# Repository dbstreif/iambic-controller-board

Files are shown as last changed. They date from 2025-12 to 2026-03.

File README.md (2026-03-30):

# Iambic Controller Custom Hardware
### (Morse Code Keyer Hardware Interface)

A board design using ATtiny85 microcontroller that interfaces with an iambic CW keyer over TRS to USB.
This project provides hardware for the firmware project found here: [Iambic-Controller](https://github.com/dbstreif/iambic-controller)

To build and install on your microcontroller, please use the Arduino IDE with the Digistump additional boards manager:
[Digistump Additional Boards Manager](https://raw.githubusercontent.com/digistump/arduino-boards-index/master/package_digistump_index.json)

### Compatibility
Plug and play with VBand, MorseIT (IOS/Android), MorseKeyer Software (PC), and many other applications.

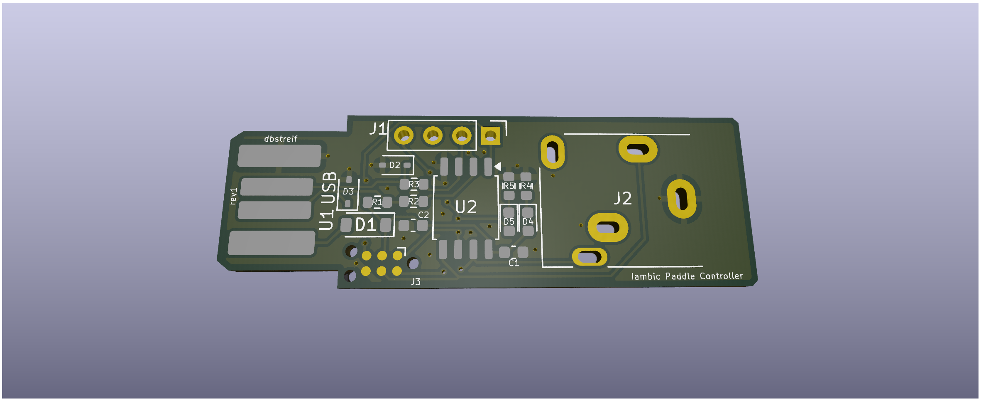
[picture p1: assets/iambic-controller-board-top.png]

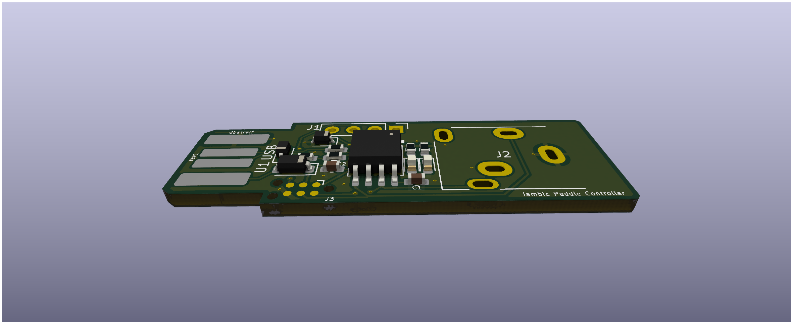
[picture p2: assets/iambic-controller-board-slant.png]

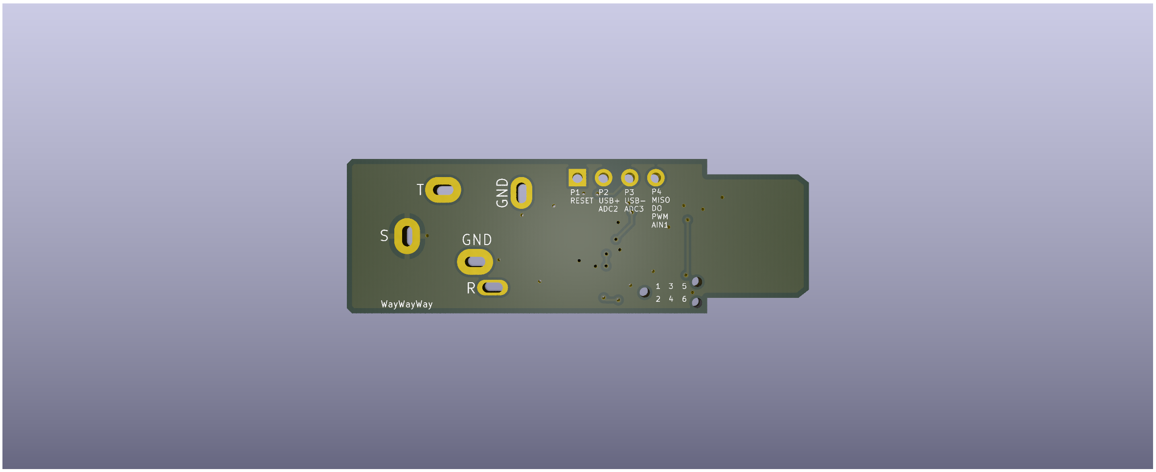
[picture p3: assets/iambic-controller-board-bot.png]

[Video of Device in Action](https://drive.google.com/file/d/1ocy6Hf0ZipwWTclOcQ86UAAeljgz8sle/view?usp=sharing)

Shield: [][cc-by]

This work is licensed under a
[Creative Commons Attribution 4.0 International License][cc-by].

[][cc-by]

[cc-by]: http://creativecommons.org/licenses/by/4.0/
[cc-by-image]: https://i.creativecommons.org/l/by/4.0/88x31.png
[cc-by-shield]: https://img.shields.io/badge/License-CC%20BY%204.0-lightgrey.svg

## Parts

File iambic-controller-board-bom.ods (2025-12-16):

Id | Designator | Footprint | Quantity | Designation | Manufacturer | MPN
1 | D5 | LED_0603_1608Metric | 1 | LED2 | Diodes Inc. | BZT52C3V6S-7-F
2 | R1 | R_0603_1608Metric | 1 | 1K5
3 | D1 | D_SOD-123 | 1 | 1N5819 | Diodes Inc. | 1N58
4 | R5,R4 | R_0603_1608Metric | 2 | 1K
5 | D4 | LED_0603_1608Metric | 1 | LED1
6 | R2,R3 | R_0603_1608Metric | 2 | 68R
7 | D2,D3 | D_SOD-323 | 2 | 3V6
8 | C1 | C_0603_1608Metric | 1 | 100nF
9 | C2 | C_0603_1608Metric | 1 | 10uF
10 | U2 | SOIC-8_5.3x5.3mm_P1.27mm | 1 | ATtiny85-20S

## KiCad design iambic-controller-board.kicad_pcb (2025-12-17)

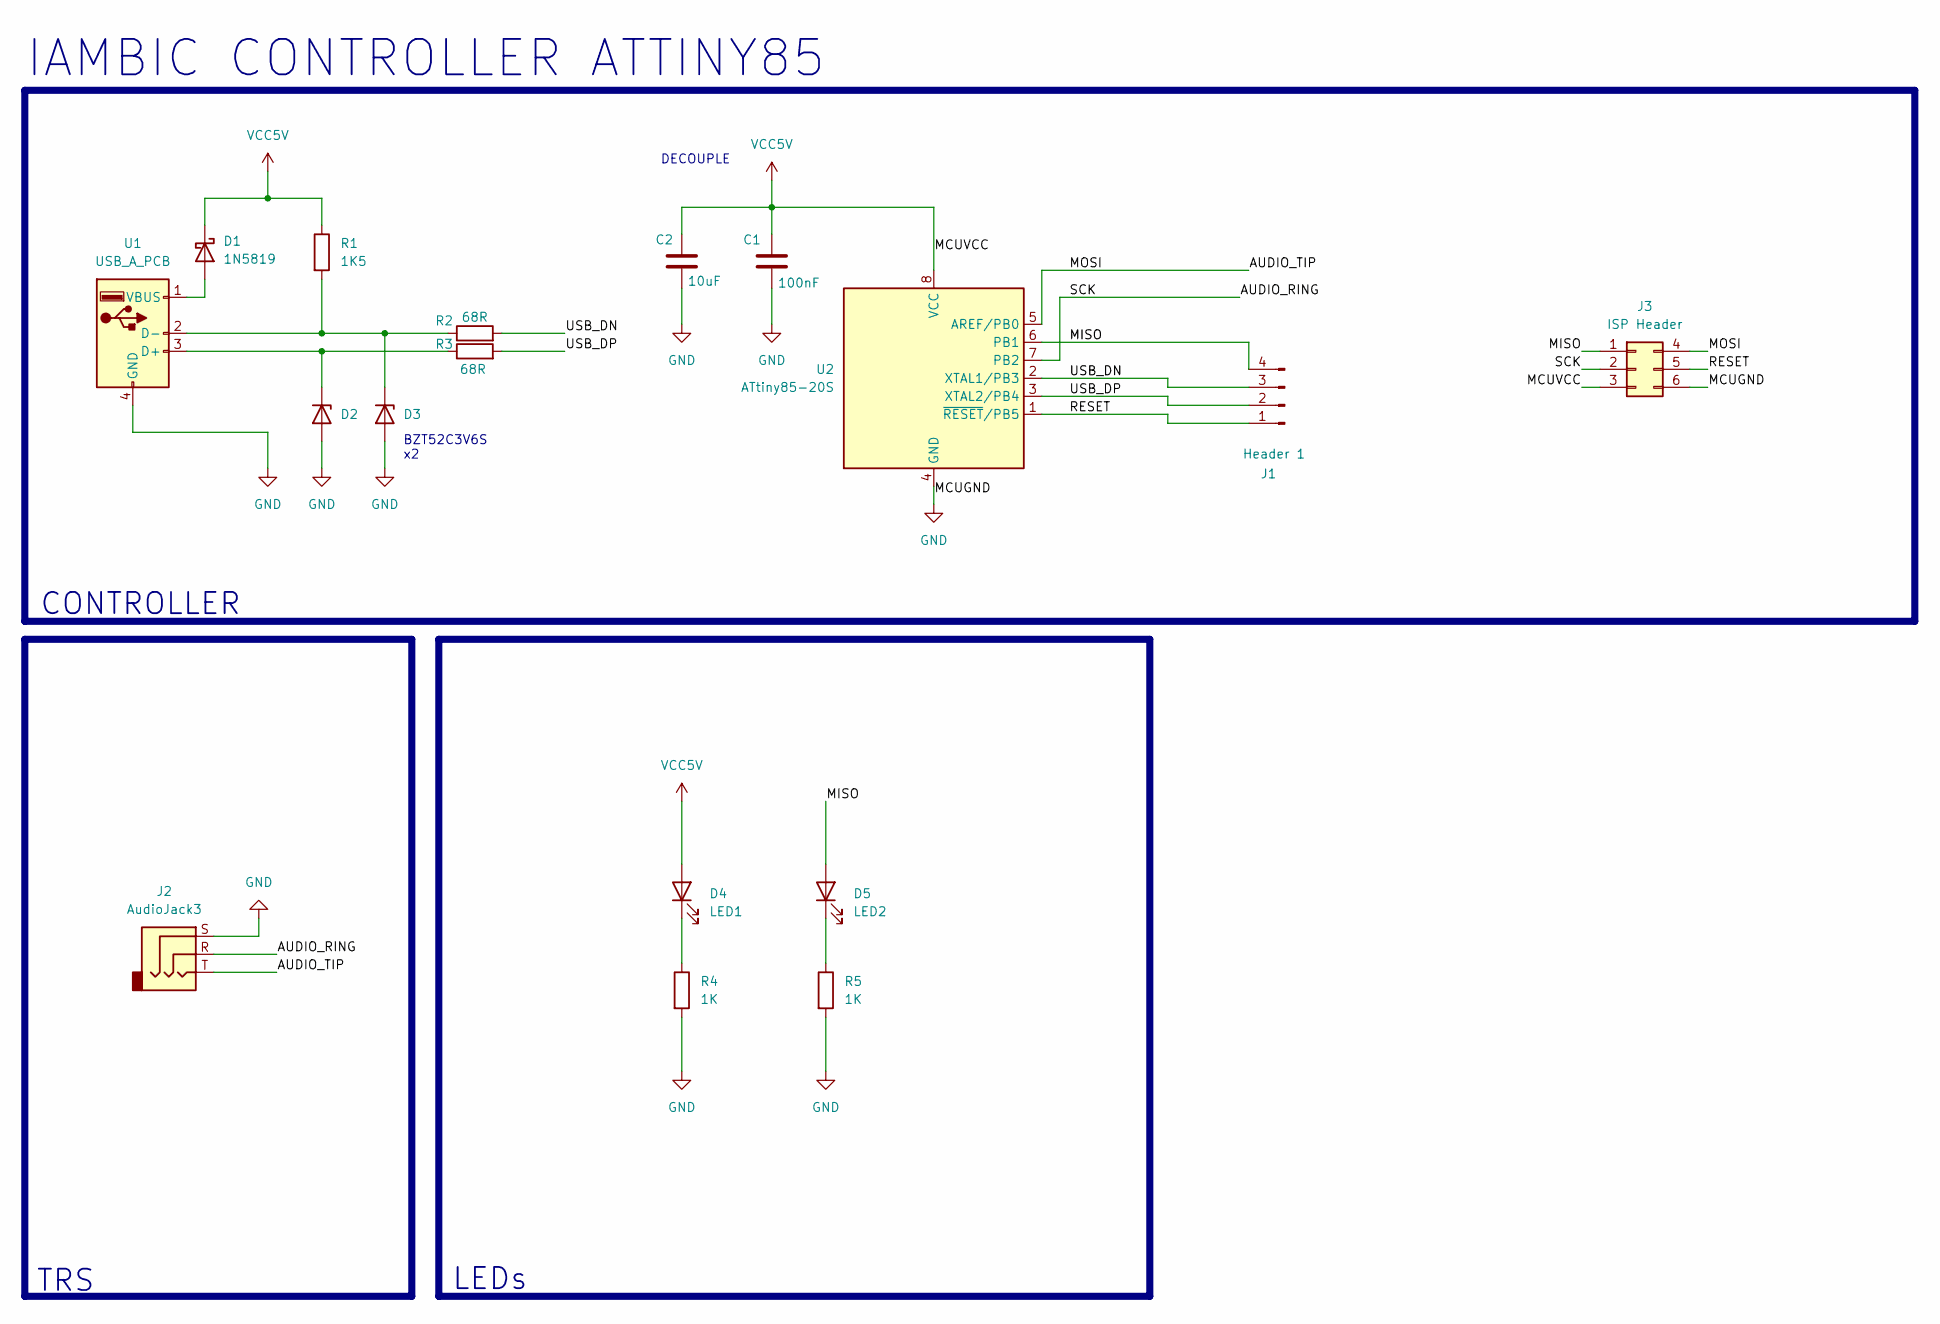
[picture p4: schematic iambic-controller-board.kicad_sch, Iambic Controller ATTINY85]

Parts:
C1: 100nF; C_0603_1608Metric
C2: 10uF; C_0603_1608Metric
D1: 1N5819; D_SOD-123
D2, D3: 3V6; D_SOD-323
D4: LED1; LED_0603_1608Metric
D5: LED2; LED_0603_1608Metric
J1: Header 1; PinHeader_1x04_P2.54mm_Vertical
J2: AudioJack3; Jack_3.5mm_CUI_SJ1-3515N_Horizontal
J3: ISP Header; Tag-Connect_TC2030-IDC-NL_2x03_P1.27mm_Vertical
R1: 1K5; R_0603_1608Metric
R2, R3: 68R; R_0603_1608Metric
R4, R5: 1K; R_0603_1608Metric
U1: USB_A_PCB; PCB_USB_A
U2: ATtiny85-20S; SOIC-8_5.3x5.3mm_P1.27mm

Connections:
/AUDIO_RING: J2.R, J3.2, U2.7 (PB2)
/AUDIO_TIP: J2.T, J3.4, U2.5 (AREF/PB0)
/MISO: D5.2 (A), J1.4, J3.1, U2.6 (PB1)
/RESET: J1.1, J3.5, U2.1 (~RESET/PB5)
/USB_DN: J1.3, R2.2, U2.2 (XTAL1/PB3)
/USB_DP: J1.2, R3.2, U2.3 (XTAL2/PB4)
GND: C1.1, C2.2, D2.2 (A), D3.2 (A), J2.S, J3.6, R4.2, R5.2, U1.4 (GND), U2.4 (GND)
unnamed: D1.2 (A), U1.1 (VBUS)
unnamed: D2.1 (K), R3.1, U1.3 (D+)
unnamed: D3.1 (K), R1.2, R2.1, U1.2 (D-)
unnamed: D4.1 (K), R4.1
unnamed: D5.1 (K), R5.1
VCC5V: C1.2, C2.1, D1.1 (K), D4.2 (A), J3.3, R1.1, U2.8 (VCC)

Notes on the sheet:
TRS
BZT52C3V6S x2
IAMBIC CONTROLLER ATTINY85
LEDs
DECOUPLE
CONTROLLER

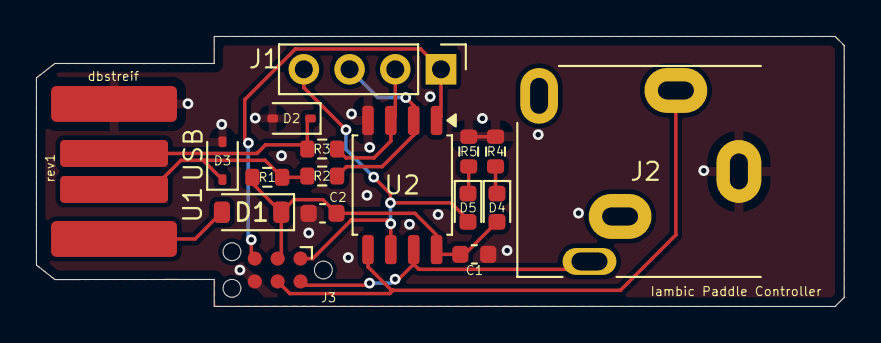
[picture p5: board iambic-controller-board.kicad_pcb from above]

Board: 2 copper layers, 44.9 x 15.0 mm, 17 parts (0 on the bottom side), 13 nets.

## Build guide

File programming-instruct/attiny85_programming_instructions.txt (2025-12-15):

Device: ATtiny85
Programming Method: ISP (In-System Programming)
Programming Voltage: 5.0V
(Note: Board has no voltage regulator; supply must be a stable 5.0V.)

ISP Pin Mapping (Connector J3):
RESET   -> J3 Pad 5
SCK     -> J3 Pad 2
MOSI    -> J3 Pad 4
MISO    -> J3 Pad 1
VCC     -> J3 Pad 3
GND     -> J3 Pad 6

Firmware File:
micronucleus-1.11.hex

Fuse Settings:
Low Fuse:       0xE1    (PLL clock, no divide, long startup)
High Fuse:      0xDD    (RESET enabled, SPI enabled, BOD-2.7V)
Extended Fuse:  0xFE    (Self-programming enabled)

Lock Bits:
0xFF    (No lock bits set; ISP fully enabled)

Instruct:
1. Program Fuses.
2. Flash micronucleus-1.11.hex using the J3 ISP header.
3. Verify programmed firmware.

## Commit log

2025-12-15 inited repo
    [iambic-controller-board-B_Cu.gbr, iambic-controller-board-B_Mask.gbr, iambic-controller-board-B_Paste.gbr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]
2025-12-15 final rev1
    [iambic-controller-board.kicad_pcb, iambic-controller-board.kicad_sch]
2025-12-15 Remove drill and gerber files from repo
    [iambic-controller-board-B_Cu.gbr, iambic-controller-board-B_Mask.gbr, iambic-controller-board-B_Paste.gbr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]
2025-12-16 Fixed weird footprints
    [iambic-controller-board-bom.ods, iambic-controller-board.kicad_pcb, iambic-controller-board.kicad_sch]
2025-12-17 fixed route
    [iambic-controller-board.kicad_pcb]
2026-03-30 Update description of PCB design in README

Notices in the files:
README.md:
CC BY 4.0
